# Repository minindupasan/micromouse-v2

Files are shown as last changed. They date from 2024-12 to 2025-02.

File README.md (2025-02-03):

# Micromouse V2

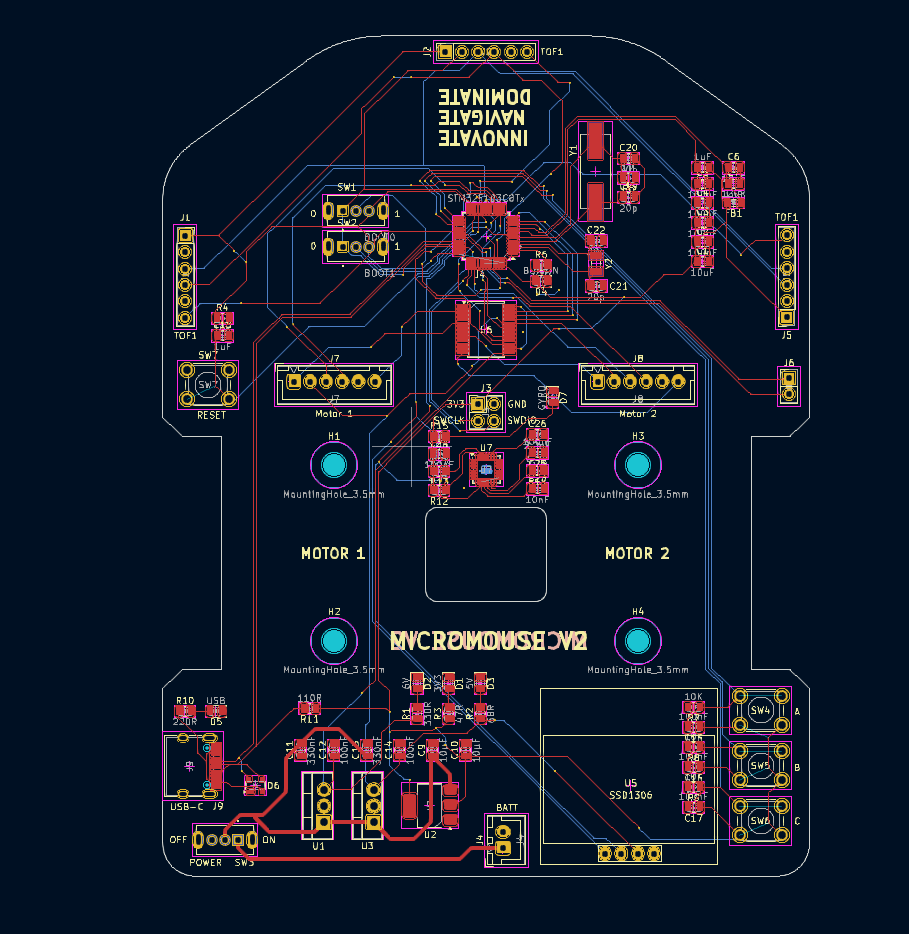
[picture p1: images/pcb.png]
PCB View

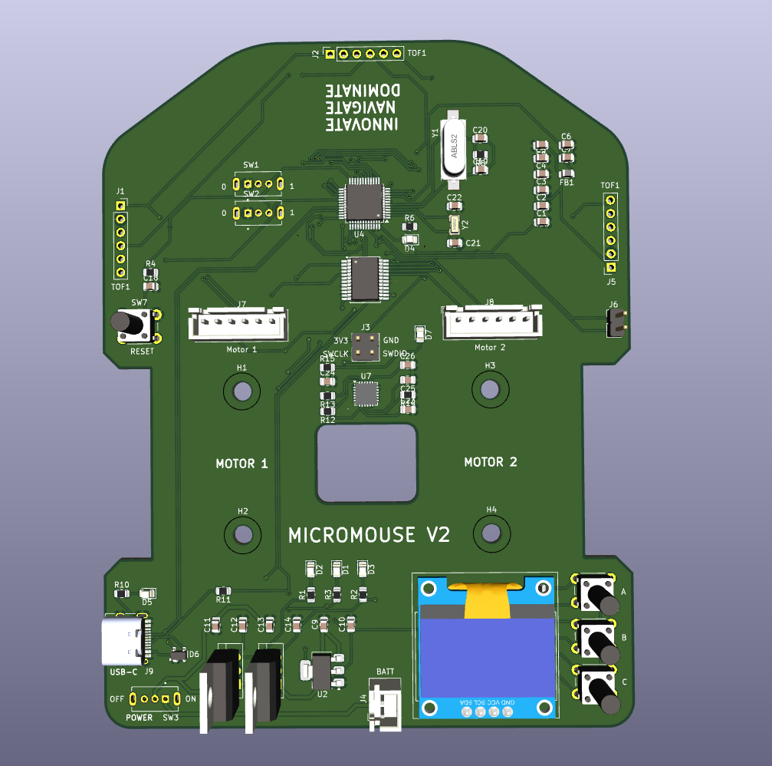
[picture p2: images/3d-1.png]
PCB 3D Top View

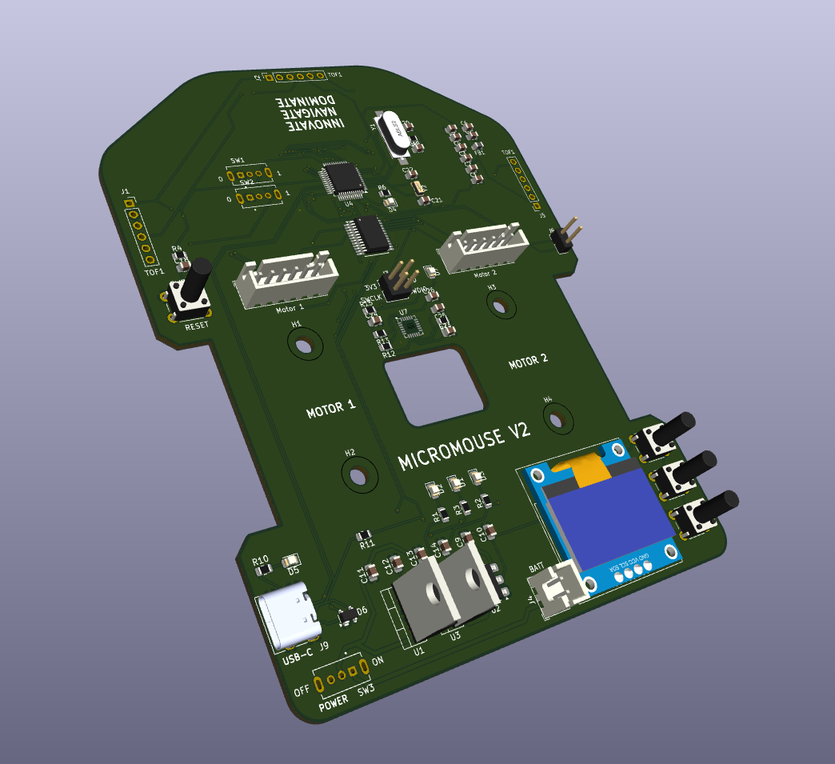
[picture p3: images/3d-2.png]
PCB 3D Angled View


This repository contains the design files, firmware, and documentation for a maze-solving car built using the STM32F103C8T6 microcontroller. The car is equipped with sensors, motors, and communication interfaces to autonomously navigate and solve mazes.

---

## Table of Contents
1. [Overview](#overview)
2. [Hardware Components](#hardware-components)
3. [PCB Design](#pcb-design)
4. [Firmware](#firmware)
5. [Communication Interfaces](#communication-interfaces)
6. [Setup and Usage](#setup-and-usage)
7. [Repository Structure](#repository-structure)
8. [License](#license)

---

## Overview

The maze-solving car is an autonomous robot designed to navigate through a maze using sensor data and decision-making algorithms. The car is built around the STM32F103C8T6 microcontroller and features the following key functionalities:
- **Maze Navigation**: Uses the MPU6050 (IMU) and VL53L0X (Time-of-Flight sensor) for orientation and distance measurement.
- **Motor Control**: TB6612FNG motor driver controls N20 motors for precise movement.
- **Debugging**: SSD1306 OLED display and UART communication for real-time debugging.
- **User Interface**: Three push buttons for menu selection and interaction.
- **Communication**: USB Type-C and UART interfaces for firmware updates and debugging.

---

## Hardware Components

### Microcontroller
- **STM32F103C8T6**: ARM Cortex-M3 based microcontroller for control and decision-making.

### Sensors
- **MPU6050**: 6-axis IMU for orientation and motion tracking.
- **VL53L0X**: Time-of-Flight (ToF) sensor for distance measurement.

### Motor Driver
- **TB6612FNG**: Dual motor driver for controlling N20 motors.

### Power Management
- **AMS1117**: 3.3V voltage regulator.
- **L7806CV**: 6V voltage regulator.
- **L7805CV**: 5V voltage regulator.

### Communication
- **USB Type-C**: For USB communication with the STM32.
- **UART Terminals**: For debugging and communication.
- **SWD (Serial Wire Debug)**: For STLink compatibility and firmware flashing.

### Other Components
- **N20 Motors**: Geared DC motors for movement.
- **SSD1306 OLED Display**: For debugging and status display.
- **Push Buttons**: Three buttons for menu selection and control.
- **SPDT Switch**: For boot mode selection.
- **Crystal Oscillators**:
  - **HSE**: 8 MHz (ABLS2-8.000MHZ-D4Y-T).
  - **LSE**: 32.768 kHz (ABS07-32.768KHZ-T).

> [!NOTE]
> The PCB design is optimized for 0805 SMD components, ensuring a compact and efficient layout.

---

## PCB Design

The PCB design files are available in the `hardware/` directory. The design includes:
- Schematic and layout files (e.g., KiCad, Altium, or Eagle).
- Gerber files for manufacturing.
- Bill of Materials (BOM) for component sourcing.

### Key Features of the PCB:
- Compact design optimized for maze-solving applications.
- Integrated power management with multiple voltage regulators.
- Debugging interfaces (UART, SWD, OLED display).
- USB Type-C for easy connectivity.

> [!TIP]
> Use the provided Gerber files for manufacturing the PCB. Ensure the manufacturer supports 2-layer boards with 1.6mm thickness.

---

## Firmware

The firmware for the maze-solving car is written in C using the STM32 HAL library. The code is located in the `firmware/` directory and includes the following features:
- **Maze Navigation Algorithm**: Implements wall-following or other maze-solving logic.
- **Sensor Integration**: Reads data from MPU6050 and VL53L0X sensors.
- **Motor Control**: Controls N20 motors using the TB6612FNG driver.
- **Debugging**: Displays real-time data on the SSD1306 OLED display.
- **User Interface**: Handles input from the push buttons.

### Dependencies
- STM32CubeMX for peripheral configuration.
- STM32 HAL library for hardware abstraction.

> [!IMPORTANT]
> Ensure the correct version of the STM32 HAL library is used to avoid compatibility issues.

> [!WARNING]
> Do not modify the STM32CubeMX configuration files manually. Always regenerate them using STM32CubeMX after making changes.

---

## Communication Interfaces

The car supports multiple communication interfaces for debugging and control:
1. **USB Type-C**: Used for firmware updates and communication with a PC.
2. **UART**: Serial communication for debugging and data logging.
3. **SWD**: For flashing firmware and debugging using STLink.

> [!TIP]
> Use a USB-to-UART converter for easy debugging via UART.

> [!CAUTION]
> Ensure the baud rate for UART communication matches between the car and the debugging tool.

---

## Setup and Usage

### Prerequisites
- STM32CubeIDE or any compatible IDE for firmware development.
- STLink or similar debugger for flashing the firmware.
- USB Type-C cable for communication and power.

### Steps to Use
1. **Flash the Firmware**:
   - Connect the STLink to the SWD terminals.
   - Open the project in STM32CubeIDE and flash the firmware.

2. **Power the Car**:
   - Connect a 7-12V power supply to the voltage regulators.

3. **Debugging**:
   - Use the UART terminals or OLED display for real-time debugging.

4. **Maze Navigation**:
   - Place the car in a maze and use the push buttons to start the navigation algorithm.

> [!WARNING]
> Double-check the polarity of the power supply connection to prevent damage to the PCB.

---

## Repository Structure
```
maze-solving-car-pcb/
├── firmware/                  # STM32 firmware source code
│   ├── Inc/                   # Header files
│   ├── Src/                   # Source files
│   └── STM32CubeMX/           # CubeMX configuration files
├── hardware/                  # PCB design files
│   ├── schematics/            # Schematic diagrams
│   ├── layout/                # PCB layout files
│   └── gerber/                # Gerber files for manufacturing
├── images/                    # Images and diagrams
├── docs/                      # Documentation and datasheets
└── README.md                  # This file
```

---

## License
This project is licensed under the MIT License. See the [LICENSE](LICENSE) file for details.

---

## Acknowledgments
- STMicroelectronics for the STM32 HAL library.
- Contributors to open-source hardware and software tools.

For questions or contributions, please open an issue or submit a pull request.

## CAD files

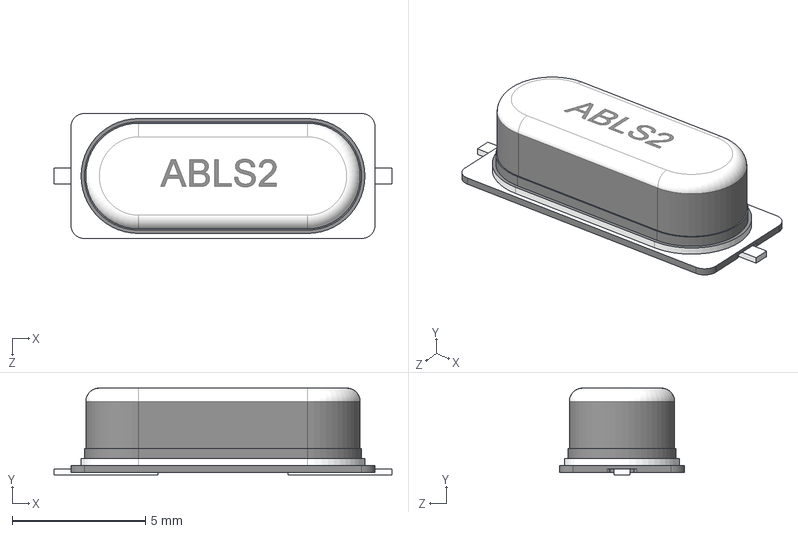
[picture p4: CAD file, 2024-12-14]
Custom Footprints and Models/ABLS2-8.000MHZ-D4Y-T/ABLS2-8.000MHZ-D4Y-T.step
12.7 x 3.27 x 4.70 mm

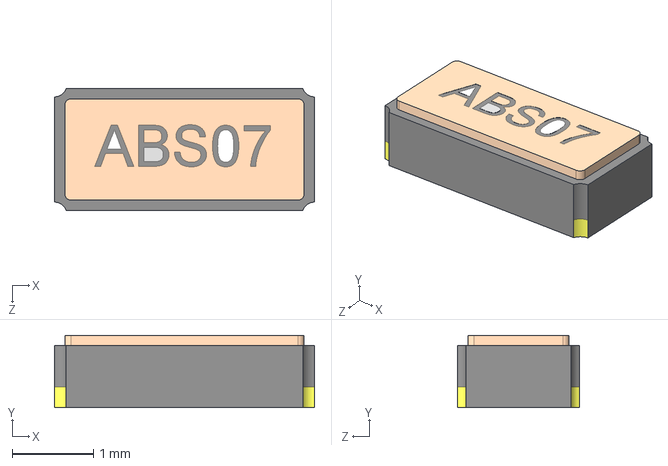
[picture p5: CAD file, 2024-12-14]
Custom Footprints and Models/ABS07-32.768KHZ-T/ABS07-32.768KHZ-T.step
3.20 x 0.889 x 1.50 mm

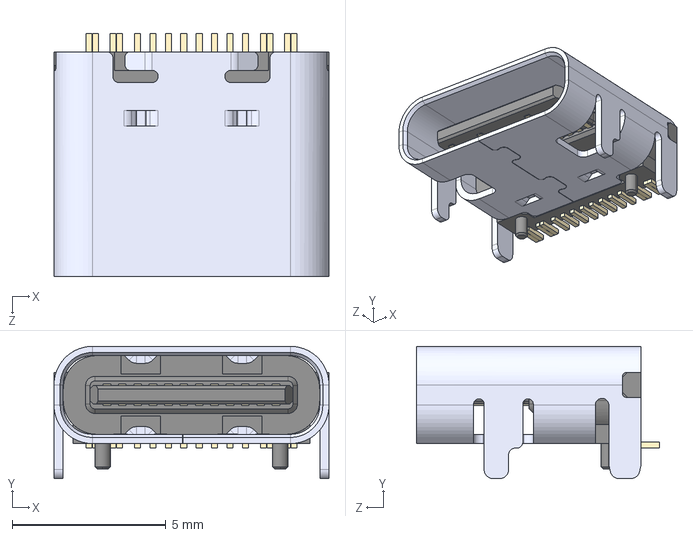
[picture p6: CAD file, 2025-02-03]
Custom Footprints and Models/TYPE-C-31-M-12--3DModel-STEP-56544.STEP
8.94 x 4.30 x 7.90 mm

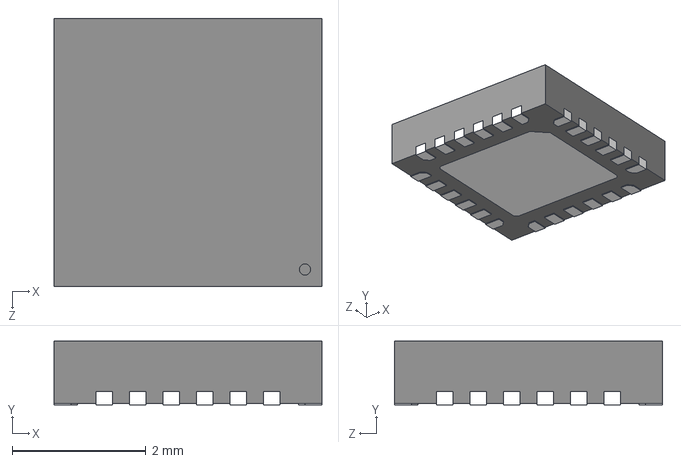
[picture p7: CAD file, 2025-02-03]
Custom Footprints and Models/MPU 6050 STEP file.STEP
4.00 x 0.95 x 4.00 mm

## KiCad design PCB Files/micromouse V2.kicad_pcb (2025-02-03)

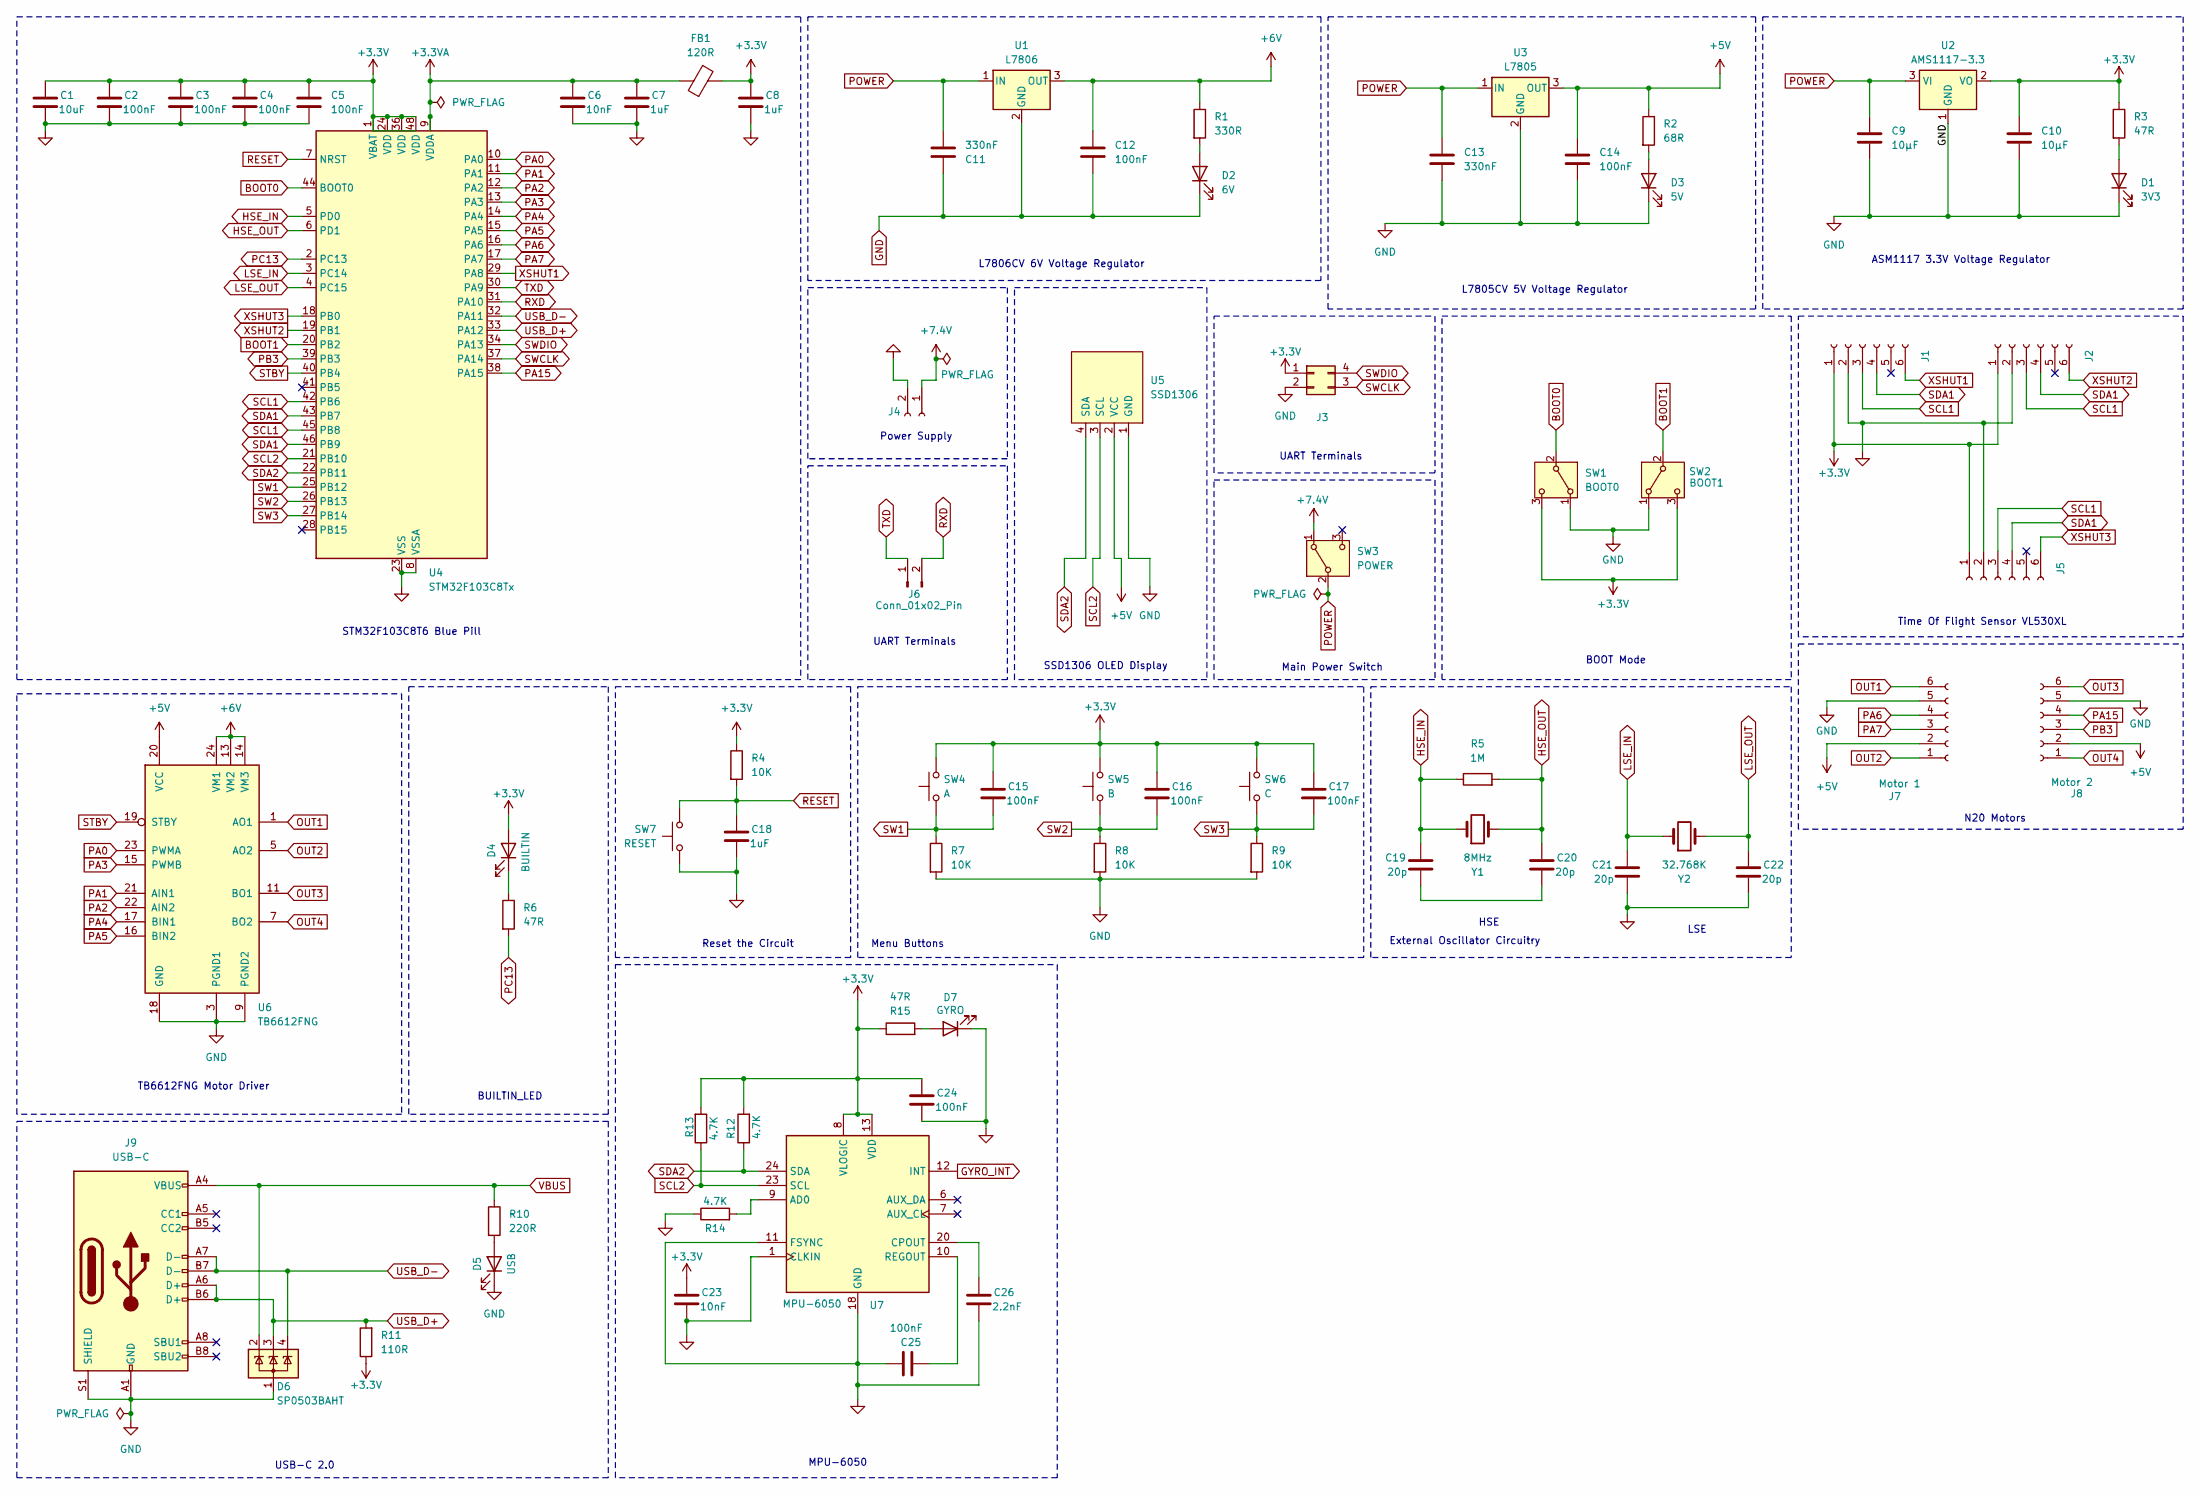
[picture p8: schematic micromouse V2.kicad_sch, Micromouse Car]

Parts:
C1: 10uF; C_0805_2012Metric; JLCPCB Part# C1713
C2, C3, C4, C5, C12, C14, C15, C16, C17, C24, C25: 100nF; C_0805_2012Metric; JLCPCB Part# C520082
C6, C23: 10nF; C_0805_2012Metric; JLCPCB Part# C519909
C7, C8, C18: 1uF; C_0805_2012Metric; JLCPCB Part# C24123
C9, C10: 10µF; C_0805_2012Metric; JLCPCB Part# C95841
C11, C13: 330nF; C_0805_2012Metric; JLCPCB Part# C318723
C19, C20, C21, C22: 20p; C_0805_2012Metric; JLCPCB Part# C1798
C26: 2.2nF; C_0805_2012Metric; JLCPCB Part# C519912
D1: 3V3; LED_0805_2012Metric; JLCPCB Part# C2297
D2: 6V; LED_0805_2012Metric; JLCPCB Part# C2297
D3: 5V; LED_0805_2012Metric; JLCPCB Part# C2297
D4: BUILTIN; LED_0805_2012Metric; JLCPCB Part# C2297
D5: USB; LED_0805_2012Metric; JLCPCB Part# C2297
D6: SP0503BAHT; SOT-143; JLCPCB Part# C7074
D7: GYRO; LED_0805_2012Metric; JLCPCB Part# C2297
FB1: 120R; L_0805_2012Metric; JLCPCB Part# C88990
J1, J2, J5: TOF1; PinSocket_1x06_P2.54mm_Vertical
J3: Conn_02x02_Counter_Clockwise; PinHeader_2x02_P2.54mm_Vertical
J4: BATT; JST_XH_B2B-XH-A_1x02_P2.50mm_Vertical; JLCPCB Part# C265283
J6: Conn_01x02_Pin; PinHeader_1x02_P2.54mm_Vertical
J7: Motor 1; JST_XH_B6B-XH-A_1x06_P2.50mm_Vertical; JLCPCB Part# C265366
J8: Motor 2; JST_XH_B6B-XH-A_1x06_P2.50mm_Vertical; JLCPCB Part# C265366
J9: USB-C; USB_C_Receptacle_HRO_TYPE-C-31-M-12; JLCPCB Part# C165948
R1: 330R; R_0805_2012Metric; JLCPCB Part# C17630
R2: 68R; R_0805_2012Metric; JLCPCB Part# C17802
R3, R6, R15: 47R; R_0805_2012Metric; JLCPCB Part# C17714
R4, R7, R8, R9: 10K; R_0805_2012Metric; JLCPCB Part# C17414
R5: 1M; R_0805_2012Metric; JLCPCB Part# C17514
R10: 220R; R_0805_2012Metric; JLCPCB Part# C17557
R11: 110R; R_0805_2012Metric; JLCPCB Part# C17423
R12, R13, R14: 4.7K; R_0805_2012Metric; JLCPCB Part# C17673
SW1: BOOT0; SW_SS12D07VG4; JLCPCB Part# C2939726
SW2: BOOT1; SW_SS12D07VG4; JLCPCB Part# C2939726
SW3: POWER; SW_SS12D07VG4; JLCPCB Part# C2939726
SW4: A; SW_PUSH_6mm_H13mm; JLCPCB Part# C7470131
SW5: B; SW_PUSH_6mm_H13mm; JLCPCB Part# C7470131
SW6: C; SW_PUSH_6mm_H13mm; JLCPCB Part# C7470131
SW7: RESET; SW_PUSH_6mm_H13mm; JLCPCB Part# C7470131
U1: L7806; TO-220-3_Vertical
U2: AMS1117-3.3; SOT-223-3_TabPin2; JLCPCB Part# C6186
U3: L7805; TO-220-3_Vertical
U4: STM32F103C8Tx; LQFP-48_7x7mm_P0.5mm; JLCPCB Part# C8734
U5: SSD1306; 128x64OLED
U6: TB6612FNG; SSOP-24_5.3x8.2mm_P0.65mm; JLCPCB Part# C141517
U7: MPU-6050; InvenSense_QFN-24_4x4mm_P0.5mm; JLCPCB Part# C24112
Y1: 8MHz; Crystal_ABLS2-8.000MHZ-D4Y-T; JLCPCB Part# C596832
Y2: 32.768K; XTAL_ABS07-32.768KHZ-T; JLCPCB Part# C130253

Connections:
+3.3V: C1.1, C2.1, C3.1, C4.1, C5.1, C8.1, C10.1, C15.1, C16.1, C17.1, C23.1, C24.1, D4.2 (A), FB1.2, J1.1, J2.1, J3.1, J5.1, R3.1, R4.1, R11.1, R12.2, R13.2, R15.1, SW1.3 (C), SW2.3 (C), SW4.2, SW5.2, SW6.2, U2.2 (VO), U4.1 (VBAT), U4.24 (VDD), U4.36 (VDD), U4.48 (VDD), U7.8 (VLOGIC), U7.13 (VDD)
+3.3VA: C6.1, C7.1, FB1.1, U4.9 (VDDA)
+5V: C14.1, J7.2, J8.2, R2.1, U3.3 (OUT), U5.2 (VCC), U6.20 (VCC)
+6V: C12.1, R1.1, U1.3 (OUT), U6.13 (VM2), U6.14 (VM3), U6.24 (VM1)
+7.4V: J4.1, SW3.1 (A)
BOOT0: SW1.2 (B), U4.44 (BOOT0)
BOOT1: SW2.2 (B), U4.20 (PB2)
GND: C1.2, C2.2, C3.2, C4.2, C5.2, C6.2, C7.2, C8.2, C9.2, C10.2, C11.1, C12.2, C13.2, C14.2, C18.2, C21.2, C22.2, C23.2, C24.2, C25.1, C26.2, D1.1 (K), D2.1 (K), D3.1 (K), D5.1 (K), D6.1 (A), D7.1 (K), J1.2, J2.2, J3.2, J4.2, J5.2, J7.5, J8.5, J9.A1 (GND), J9.A12 (GND), J9.B1 (GND), J9.B12 (GND), J9.S1 (SHIELD), R7.2, R8.2, R9.2, R14.1, SW1.1 (A), SW2.1 (A), SW7.1, U1.2 (GND), U2.1 (GND), U3.2 (GND), U4.8 (VSSA), U4.23 (VSS), U4.35 (VSS), U4.47 (VSS), U5.1 (GND), U6.3 (PGND1), U6.4 (PGND1), U6.9 (PGND2), U6.10 (PGND2), U6.18 (GND), U7.1 (CLKIN), U7.11 (FSYNC), U7.18 (GND)
GYRO_INT: U7.12 (INT)
HSE_IN: C19.1, R5.1, U4.5 (PD0), Y1.1
HSE_OUT: C20.1, R5.2, U4.6 (PD1), Y1.2
LSE_IN: C21.1, U4.3 (PC14), Y2.1
LSE_OUT: C22.1, U4.4 (PC15), Y2.2
unnamed: C19.2, C20.2
unnamed: D1.2 (A), R3.2
unnamed: D2.2 (A), R1.2
unnamed: D3.2 (A), R2.2
unnamed: D4.1 (K), R6.1
unnamed: D5.2 (A), R10.2
unnamed: D7.2 (A), R15.2
unnamed: R14.2, U7.9 (AD0)
unnamed: C26.1, U7.20 (CPOUT)
unnamed: C25.2, U7.10 (REGOUT)
OUT1: J7.6, U6.1 (AO1), U6.2 (AO1)
OUT2: J7.1, U6.5 (AO2), U6.6 (AO2)
OUT3: J8.6, U6.11 (BO1), U6.12 (BO1)
OUT4: J8.1, U6.7 (BO2), U6.8 (BO2)
PA0: U4.10 (PA0), U6.23 (PWMA)
PA1: U4.11 (PA1), U6.21 (AIN1)
PA2: U4.12 (PA2), U6.22 (AIN2)
PA3: U4.13 (PA3), U6.15 (PWMB)
PA4: U4.14 (PA4), U6.17 (BIN1)
PA5: U4.15 (PA5), U6.16 (BIN2)
PA6: J7.4, U4.16 (PA6)
PA7: J7.3, U4.17 (PA7)
PA15: J8.4, U4.38 (PA15)
PB3: J8.3, U4.39 (PB3)
PC13: R6.2, U4.2 (PC13)
POWER: C9.1, C11.2, C13.1, SW3.2 (B), U1.1 (IN), U2.3 (VI), U3.1 (IN)
RESET: C18.1, R4.2, SW7.2, U4.7 (NRST)
RXD: J6.2, U4.31 (PA10)
SCL1: J1.3, J2.3, J5.3, U4.42 (PB6), U4.45 (PB8)
SCL2: R13.1, U4.21 (PB10), U5.3 (SCL), U7.23 (SCL)
SDA1: J1.4, J2.4, J5.4, U4.43 (PB7), U4.46 (PB9)
SDA2: R12.1, U4.22 (PB11), U5.4 (SDA), U7.24 (SDA)
STBY: U4.40 (PB4), U6.19 (STBY)
SW1: C15.2, R7.1, SW4.1, U4.25 (PB12)
SW2: C16.2, R8.1, SW5.1, U4.26 (PB13)
SW3: C17.2, R9.1, SW6.1, U4.27 (PB14)
SWCLK: J3.3, U4.37 (PA14)
SWDIO: J3.4, U4.34 (PA13)
TXD: J6.1, U4.30 (PA9)
USB_D+: D6.3 (K), J9.A6 (D+), J9.B6 (D+), R11.2, U4.33 (PA12)
USB_D-: D6.4 (K), J9.A7 (D-), J9.B7 (D-), U4.32 (PA11)
VBUS: D6.2 (K), J9.A4 (VBUS), J9.A9 (VBUS), J9.B4 (VBUS), J9.B9 (VBUS), R10.1
XSHUT1: J1.6, U4.29 (PA8)
XSHUT2: J2.6, U4.19 (PB1)
XSHUT3: J5.6, U4.18 (PB0)

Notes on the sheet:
Main Power Switch
Menu Buttons
Time Of Flight Sensor VL530XL
SSD1306 OLED Display
UART Terminals
ASM1117 3.3V Voltage Regulator
Power Supply
LSE
USB-C 2.0
STM32F103C8T6 Blue Pill
External Oscillator Circuitry
BUILTIN_LED
Reset the Circuit
L7806CV 6V Voltage Regulator
TB6612FNG Motor Driver
HSE
MPU-6050
N20 Motors
BOOT Mode
L7805CV 5V Voltage Regulator

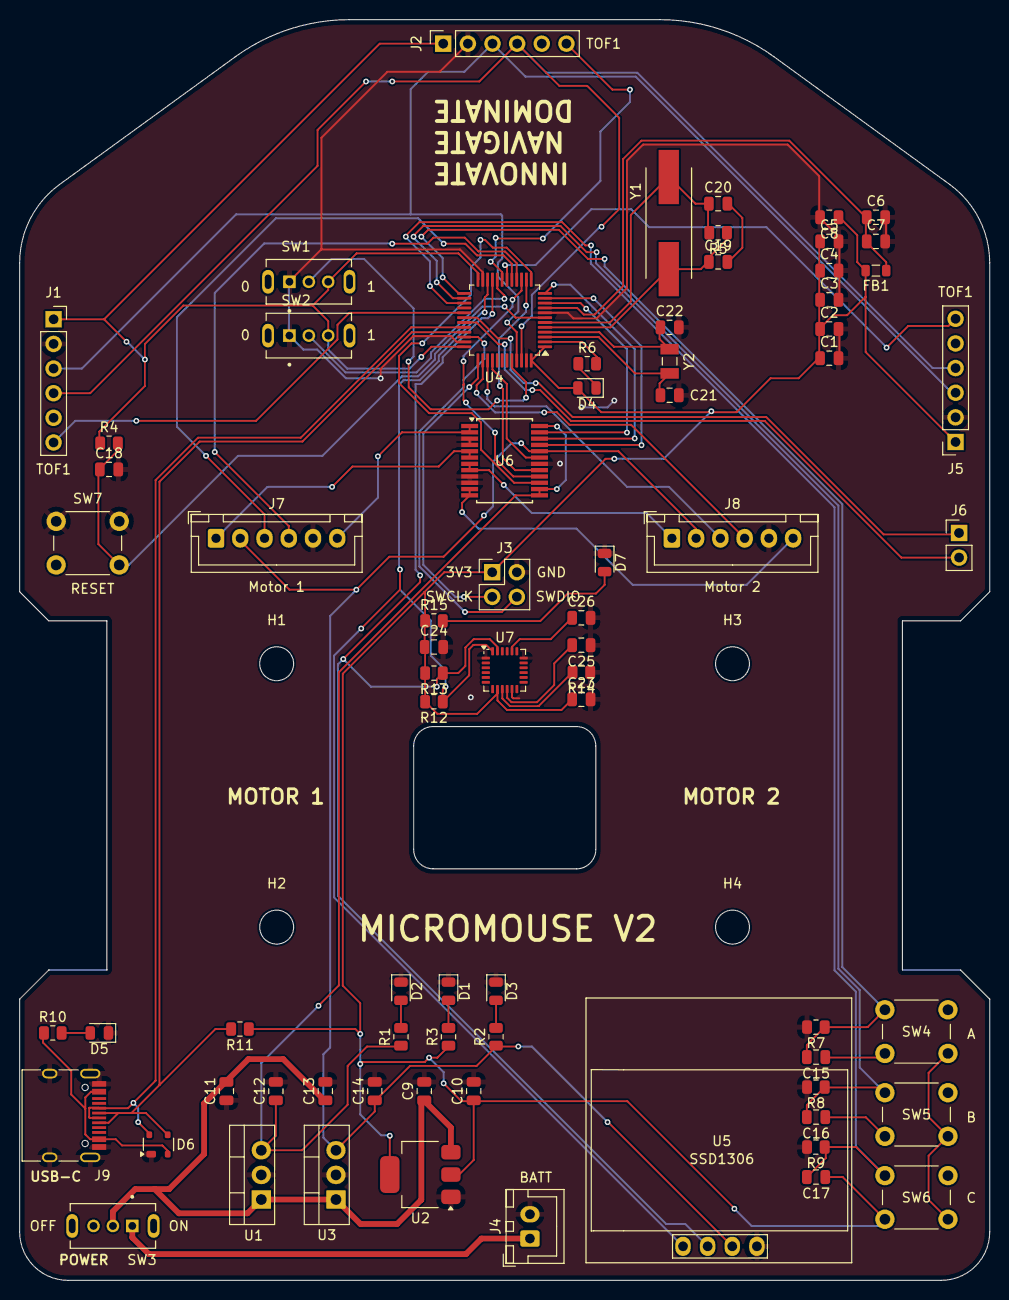
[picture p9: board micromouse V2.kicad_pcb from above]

Board: 2 copper layers, 100.0 x 130.0 mm, 78 parts (0 on the bottom side), 57 nets.

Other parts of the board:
H1, H2, H3, H4: MountingHole_3.5mm

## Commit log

2024-12-14 Added PCB files for Micromouse project
    [Micromouse.csv, micromouse V2.kicad_pcb, micromouse V2.kicad_sch]
2024-12-14 Assigned HSE and LSE Oscillators
    HSE - ABLS2-8.000MHZ-D4Y-T
    LSE - ABS07-32.768KHZ-T
    [ABLS2-8.000MHZ-D4Y-T.step, ABS07-32.768KHZ-T.step]
2024-12-15 Fixed PCB Layout
    [micromouse V2.kicad_pcb, micromouse V2.kicad_sch]
2024-12-30 Flipped TOF
    [micromouse V2.kicad_pcb]
2025-02-03 Removed unused files
    [Micromouse.csv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]
2025-02-03 Modified the text in pcb
    [micromouse V2.kicad_pcb]
2025-02-03 Rename Screenshot 2025-02-03 at 18.57.03.png to pcb-front
